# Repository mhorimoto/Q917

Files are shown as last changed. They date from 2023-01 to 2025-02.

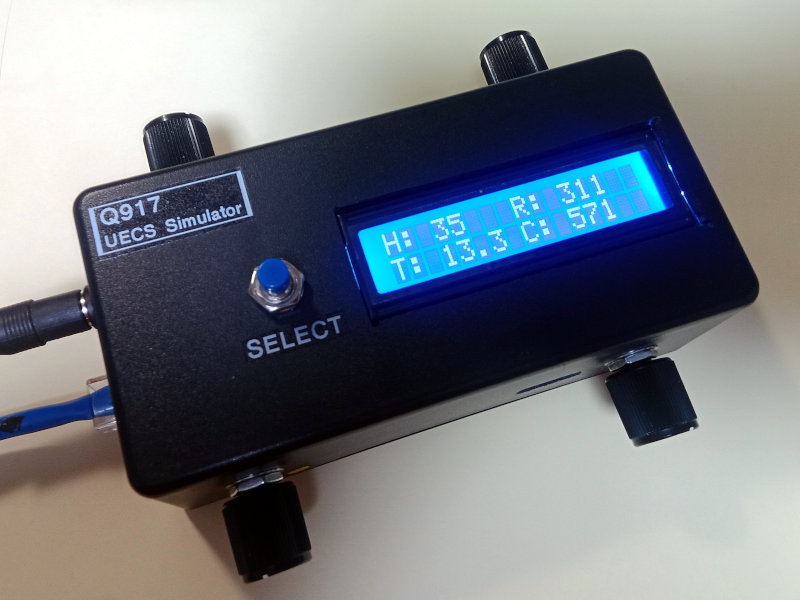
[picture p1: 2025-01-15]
Q917/q917out.jpg

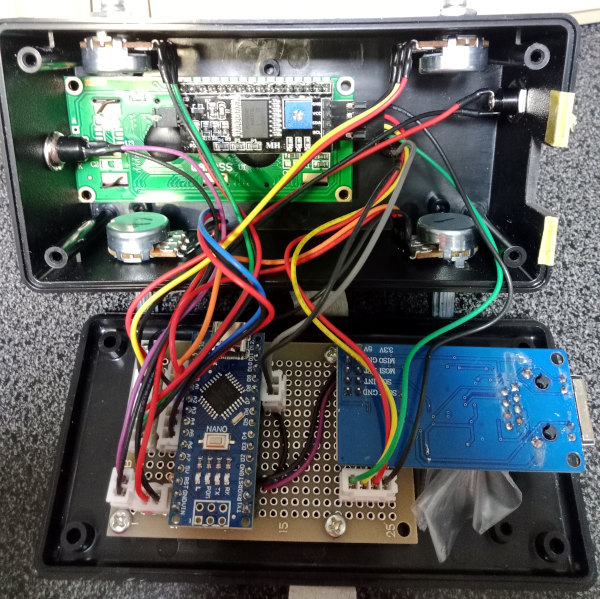
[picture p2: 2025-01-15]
Q917/q917in.jpg

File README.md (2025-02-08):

# Q917
UECSシミュレータ

4chのアナログデータをUECSパケットにして送信する。

## H/W諸元

* CPU: Arduino UNO R3
* LAN: W5500
* LCD: 16x2
* CASE: TAKACHI TW9-4-17-B

## UECS諸元

* UECS-ID: 10100C00000C
* MAC Address: 02:A2:73:0C:xx:xx

## Low core memory (EEPROM)

UECS-IDとMACアドレスを以下のアドレスに記録する．MSB first，Big endianにて記録す
る．

|  Address | Data |
|:---:|:---|
| 00H〜05H | UECS-ID |
| 06H〜0BH | MAC Address |
| 0CH〜1FH | Reserved |
| 20H〜7FFFH | Data |

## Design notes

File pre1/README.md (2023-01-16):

# pre1
4chのAnalog Inputの入力を行い、気温や湿度に尤もらしい変換を行ってLCD表示を行う部分を実装している。

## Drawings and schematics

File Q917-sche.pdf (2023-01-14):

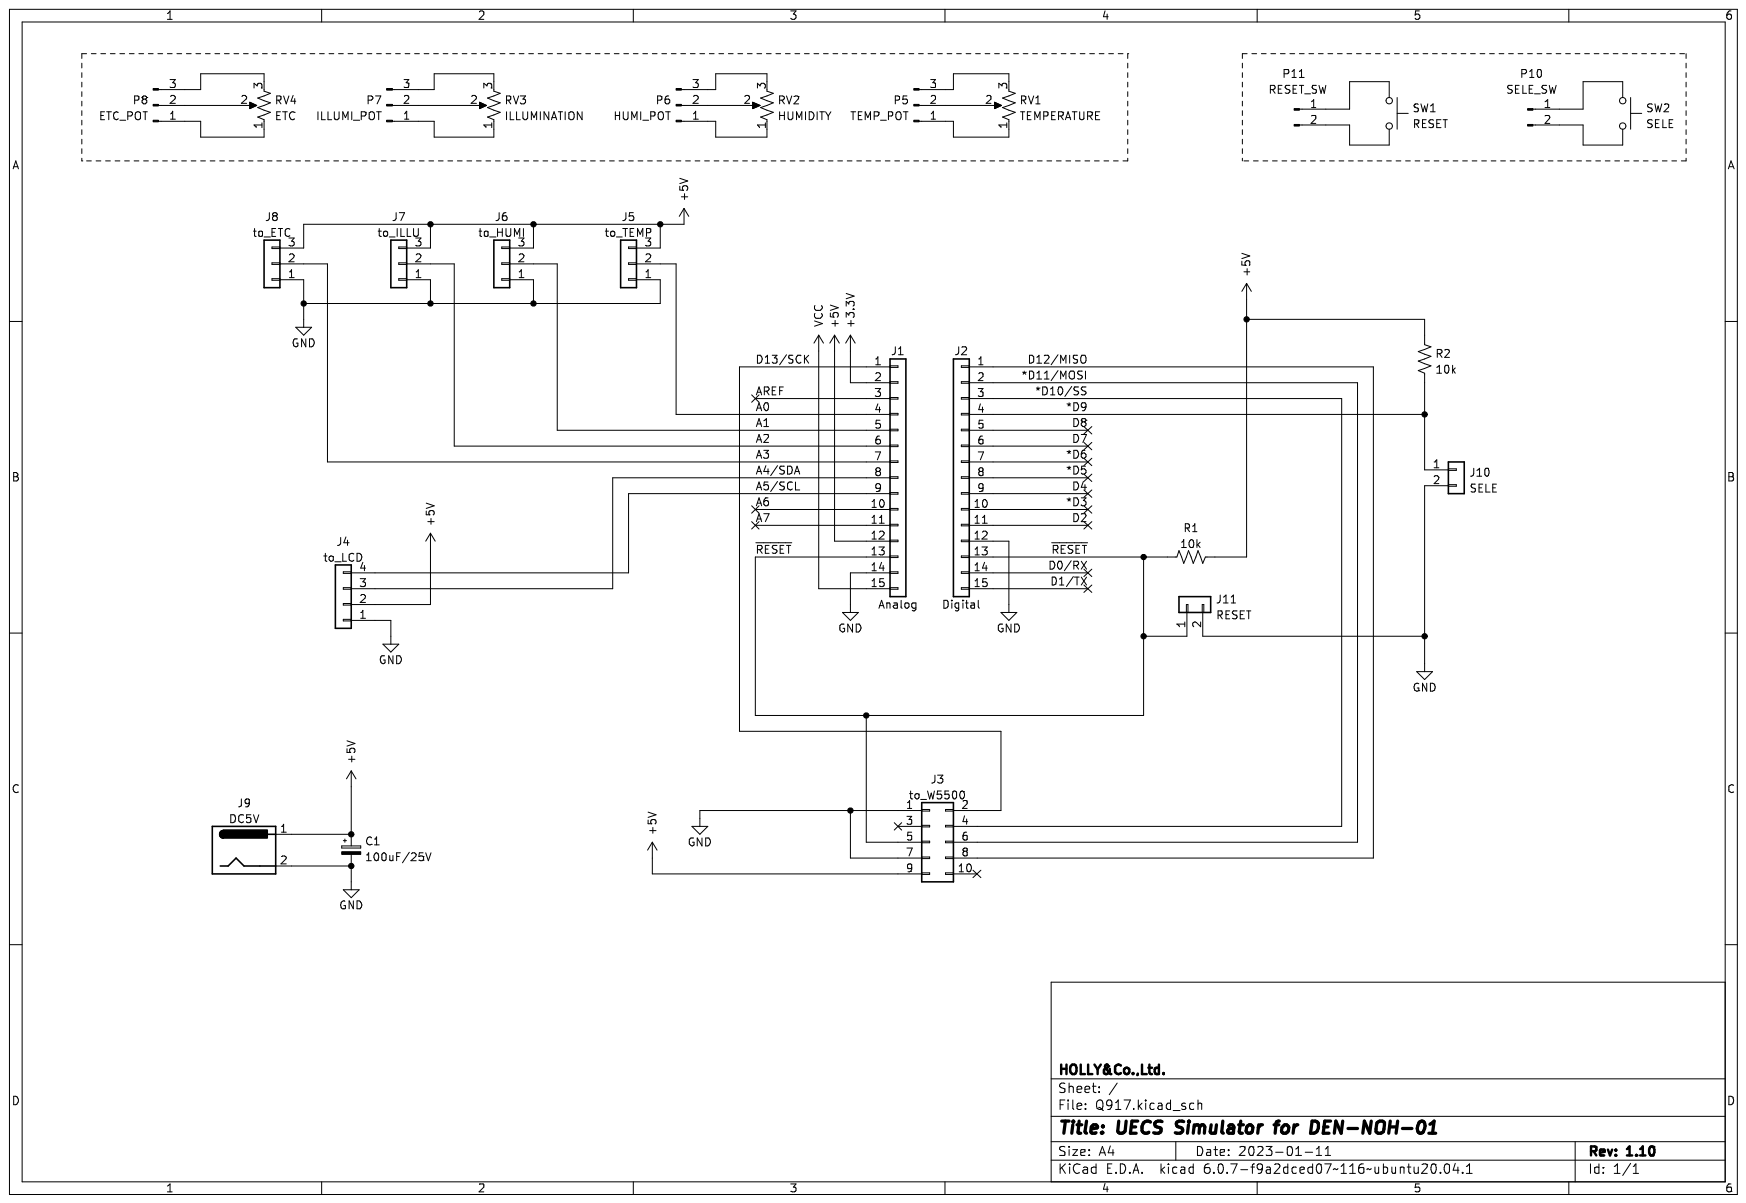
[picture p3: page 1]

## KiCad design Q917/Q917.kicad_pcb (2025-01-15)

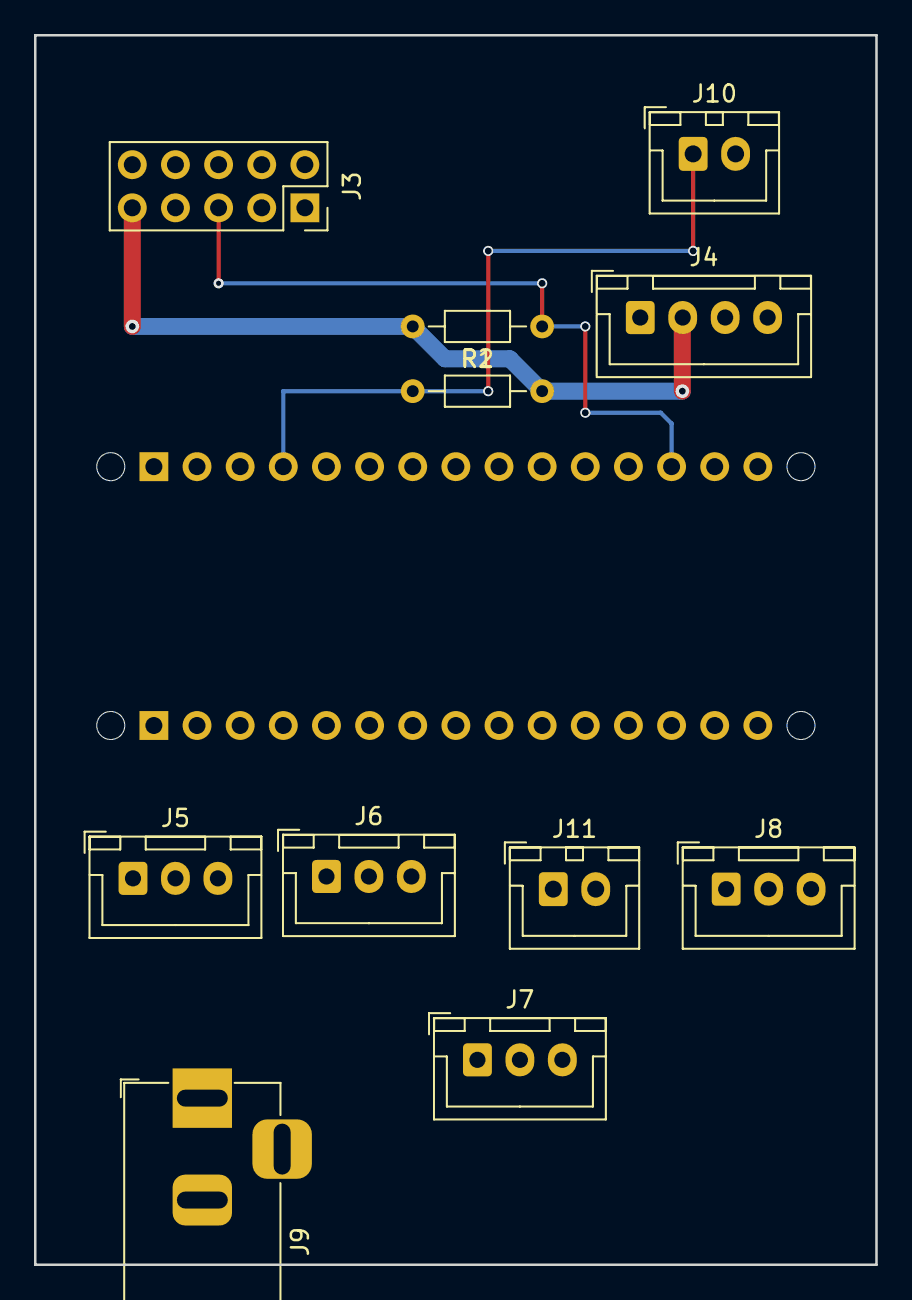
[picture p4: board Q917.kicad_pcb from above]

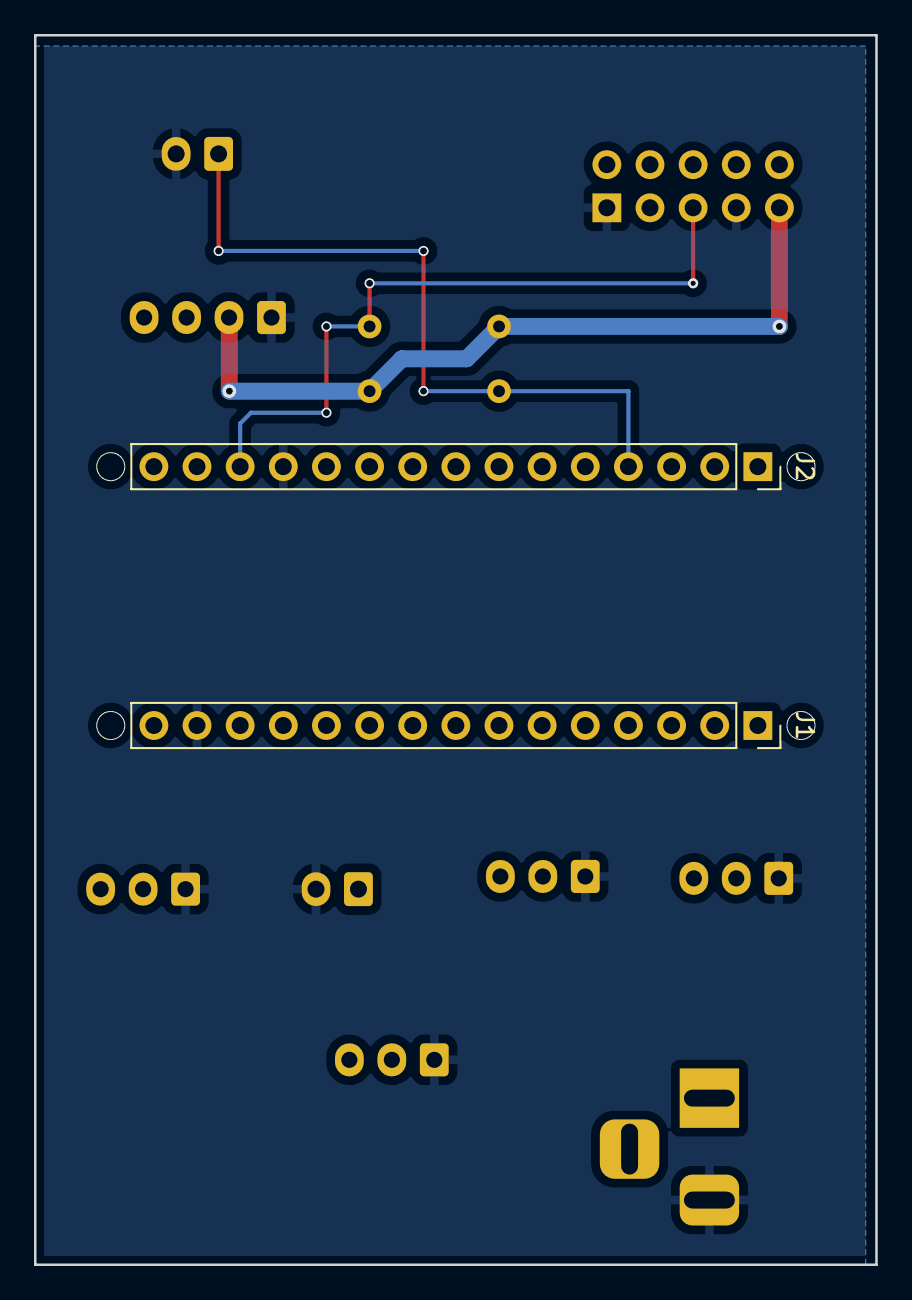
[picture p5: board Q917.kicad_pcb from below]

Board: 2 copper layers, 49.5 x 72.4 mm, 17 parts (2 on the bottom side), 14 nets.

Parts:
J1: Analog; PinSocket_1x15_P2.54mm_Vertical
J2: Digital; PinSocket_1x15_P2.54mm_Vertical
J3: to_W5500; PinSocket_2x05_P2.54mm_Vertical
J4: to_LCD; JST_XH_B4B-XH-A_1x04_P2.50mm_Vertical
J5: to_TEMP; JST_XH_B3B-XH-A_1x03_P2.50mm_Vertical
J6: to_HUMI; JST_XH_B3B-XH-A_1x03_P2.50mm_Vertical
J7: to_ILLU; JST_XH_B3B-XH-A_1x03_P2.50mm_Vertical
J8: to_ETC; JST_XH_B3B-XH-A_1x03_P2.50mm_Vertical
J9: DC5V; BarrelJack_Horizontal
J10: SELE; JST_XH_B2B-XH-A_1x02_P2.50mm_Vertical
J11: RESET; JST_XH_B2B-XH-A_1x02_P2.50mm_Vertical
MH1, MH2, MH3, MH4: MountingHole_65mil
R1, R2: 10k; R_Axial_DIN0204_L3.6mm_D1.6mm_P7.62mm_Horizontal

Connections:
+5V: J1.12, J3.9, J4.2, J5.3, J6.3, J7.3, J8.3, J9.1, R1.2, R2.2
/*D9: J2.4, J10.1, R2.1
/*D10/SS: J2.3, J3.4
/*D11/MOSI: J2.2, J3.6
/A0: J1.4, J5.2
/A1: J1.5, J6.2
/A2: J1.6, J7.2
/A3: J1.7, J8.2
/A4/SDA: J1.8, J4.3
/A5/SCL: J1.9, J4.4
/D12/MISO: J2.1, J3.8
/D13/SCK: J1.1, J3.2
/~RESET: J1.13, J2.13, J3.5, J11.1, R1.1
GND: J1.14, J2.12, J3.1, J3.7, J4.1, J5.1, J6.1, J7.1, J8.1, J9.2, J10.2, J11.2

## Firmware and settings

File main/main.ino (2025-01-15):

#include <Wire.h>
#include <LiquidCrystal_I2C.h>
#include <EEPROM.h>
#include <SPI.h>
#include <Ethernet2.h>
#include <EthernetUdp2.h> // UDP library from: bjoern@cs.stanford.edu 12/30/2008

LiquidCrystal_I2C lcd(0x27,16,2);

EthernetClient client;

byte   lcdf;
uint8_t mac[6];
//uint8_t ip[] = {192,168,35,2};   // 先頭を0にするとDHCPで決定する。
uint8_t ip[] = {0,168,35,2};   // 先頭を0にするとDHCPで決定する。
uint8_t nmask[]  = {255,255,255,0};
uint8_t nullip[] = {0,0,0,0};
char *txt[4][2];  // [screen][rows][columns]
char strIP[16];
char uecsid[6], uecstext[180],linebuf[80];
IPAddress localIP,broadcastIP,subnetmaskIP,remoteIP;
EthernetUDP Udp16520;
int period1sec,period10sec,period60sec;

void setup(void) {
  int i;
  char z[17];
  txt[0][0] = "UECS Simulator  ";
  txt[0][1] = "Q917 Ver:2.00   ";
  txt[1][0] = "DATA DRIVEN     ";
  txt[1][1] = "AGRICULTURE     ";
  txt[2][0] = "MAC Address     ";
  txt[2][1] = "IP Address      ";
  txt[3][0] = "0000.0000.0000  ";
  txt[3][1] = "000.000.000.000 ";
  lcd.init();
  lcd.backlight();
  lcdout(0,0,1,1);
  delay(1500);
  sprintf(txt[1][1],"ID:%02X%02X%02X%02X%02X%02X",
	  EEPROM.read(0),EEPROM.read(1),EEPROM.read(2),
	  EEPROM.read(3),EEPROM.read(4),EEPROM.read(5));
  lcdout(1,0,1,1);
  delay(1500);
  lcdout(2,0,1,1);
  delay(500);
  for (i=0;i<6;i++) {
    mac[i] = EEPROM.read(i+6);
  }
  Ethernet.init(10);// CS pin 10
  sprintf(txt[3][0],"%02X%02X.%02X%02X.%02X%02X",
	  mac[0],mac[1],mac[2],mac[3],mac[4],mac[5]);
  lcdout(3,0,1,1);
  delay(500);
  if (ip[0]==0) {
    if (Ethernet.begin(mac) == 0) {
      lcd.setCursor(0,1);
      sprintf(txt[3][1],"NFL");
    }
  } else {
    Ethernet.begin(mac,ip,nullip,nullip,nmask);
  }
  localIP = Ethernet.localIP();
  subnetmaskIP = Ethernet.subnetMask();
  for(i=0;i<4;i++) {
    broadcastIP[i] = ~subnetmaskIP[i]|localIP[i];
  }
  sprintf(strIP,"%d.%d.%d.%d",localIP[0],localIP[1],localIP[2],localIP[3]);
  sprintf(txt[3][1],"%s",strIP);
  lcdout(3,0,1,1);
  Udp16520.begin(16520);
  delay(1000);
  lcd.clear();
  pinMode(A0,INPUT);
  pinMode(A1,INPUT);
  pinMode(A2,INPUT);
  pinMode(A3,INPUT);
  pinMode(9,INPUT);
  lcdf = 0;
  period1sec  = 0;
  period10sec = 0;
  period60sec = 0;
}

void loop(void) {
  int a1,a2,a3,a4,a1b,a1c;
  char s1[6],s2[6],s3[6],s4[6];
  static unsigned long msec,p1msec,p10msec,p60msec;
  long li;
  float fl;

  if (digitalRead(9)==LOW) {
    if (lcdf==1) {
      lcdf = 0;
      lcd.clear();
    }
  } else {
    if (lcdf==0) {
      lcdf = 1;
      lcd.clear();
    }
  }
  a1 = analogRead(A0);
  li = map(a1,0,1022,-100,500);
  a1b = (int)(li/10);
  a1c = (int)(li-(a1b*10));
  a2 = analogRead(A1);
  li = map(a2,0,1022,0,100);
  a2 = (int)li;
  a3 = analogRead(A2);
  li = map(a3,0,1023,0,1300);
  a3 = (int)li;
  a4 = analogRead(A3);
  li = map(a4,0,1023,200,2000);
  a4 = (int)li;
  
  sprintf(s1,"%3d.%01d",a1b,abs(a1c));  // Temp
  sprintf(s2,"%3d",a2);                 // Humi
  sprintf(s3,"%4d",a3);                 // Radiation
  sprintf(s4,"%4d",a4);                 // CO2
  if (lcdf==1) {
    lcd.setCursor(0,1);
    lcd.print("T:");
    lcd.setCursor(0,0);
    lcd.print("R:");
    lcd.setCursor(10,0);
    lcd.print("C:");
    lcd.setCursor(10,1);
    lcd.print("H:");
    lcd.setCursor(2,1);
    lcd.print(s1);
    lcd.setCursor(13,1);
    lcd.print(s2);
    lcd.setCursor(2,0);
    lcd.print(s3);
    lcd.setCursor(12,0);
    lcd.print(s4);
  } else {
    lcd.setCursor(0,0);
    lcd.print("IP Address");
    lcd.setCursor(0,1);
    lcd.print(strIP);
  }
  sprintf(s1,"%d.%01d",a1b,abs(a1c));
  sprintf(s2,"%d",a2);
  sprintf(s3,"%d",a3);
  sprintf(s4,"%d",a4);
  msec = millis();
  if ((msec-p1msec)>=1000) {
    period1sec = 1;
    p1msec = msec;
  }
  if ((msec-p10msec)>=10000) {
    period10sec = 1;
    p10msec = msec;
  }
  if ((msec-p60msec)>=60000) {
    period60sec = 1;
    p60msec = msec;
  }
  if (period1sec==1) UserEvery1Sec(s1,s2,s3,s4);
  if (period10sec==1) UserEvery10Sec();
  if (period60sec==1) UserEveryMinute();
}

void UserEvery1Sec(char s1[],char s2[],char s3[],char s4[]) {
  period1sec = 2;
  uecsSendData(0x10,s1);
  delay(30);
  uecsSendData(0x30,s2);
  delay(30);
  uecsSendData(0x50,s3);
  delay(30);
  uecsSendData(0x70,s4);
  delay(30);
  uecsSendData(0x90,"0");
  delay(30);
  period1sec = 0;
}

void UserEvery10Sec() {
  period10sec = 2;
  period10sec = 0;
}

void UserEveryMinute() {
  period60sec = 2;
  period60sec = 0;
}

void lcdout(int m,int l1,int l2,int cl) {
  if (cl!=0) {
    lcd.clear();
  }
  lcd.setCursor(0,0);
  lcd.print(txt[m][l1]);
  lcd.setCursor(0,1);
  lcd.print(txt[m][l2]);
}

void uecsSendData(int a,char *val) {
  const char *xmlDT PROGMEM = "<?xml version=\"1.0\"?><UECS ver=\"1.00-E10\"><DATA type=\"%s\" room=\"%d\" region=\"%d\" order=\"%d\" priority=\"%d\">%s</DATA><IP>%s</IP></UECS>";
  byte room,region,order,priority,interval;
  int  i;
  char name[26],dname[26]; // ,val[6];
  EEPROM.get(a+0x01,room);
  EEPROM.get(a+0x02,region);
  EEPROM.get(a+0x03,order);
  EEPROM.get(a+0x05,priority);
  EEPROM.get(a+0x06,interval);
  EEPROM.get(a+0x07,name);
  for(i=0;i<25;i++) {
    dname[i] = name[i];
    if (name[i]==NULL) break;
  }
  dname[i] = NULL;
  sprintf(uecstext,xmlDT,dname,room,region,order,priority,val,strIP);
  Udp16520.beginPacket(broadcastIP,16520);
  Udp16520.write(uecstext);
  Udp16520.endPacket();
}

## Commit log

2023-01-09 sche: ちょっと書いた
    [Q917.kicad_pcb, Q917.kicad_sch]
2023-01-10 sche: コネクタ類に変更
    [Q917.kicad_sch]
2023-01-10 sche: 初版完成
    [Q917.kicad_sch]
2023-01-10 sche: PCB配線開始
    [Q917.kicad_pcb, Q917.kicad_sch]
2023-01-14 docs: sche図をPDF更新
2023-01-16 prog: 書き始め
2023-01-16 prog: 予備的プログラム作成
2023-01-18 prog:少し追加
2023-01-31 prog: Ethernetを追記中
2023-12-26 リリース
    [Q917.kicad_pcb, Q917.kicad_sch]
2024-03-24 VRの文字盤を追加
2024-03-24 2024/3/28 セミナー対応
2024-03-24 セミナー用の設定完
2024-09-23 KiCAD Version match
    [Q917.kicad_pcb]
2024-10-31 KiCAD: 8.0.6
    [Q917.kicad_pcb, Q917.kicad_sch]
2024-11-25 ラベル作成
